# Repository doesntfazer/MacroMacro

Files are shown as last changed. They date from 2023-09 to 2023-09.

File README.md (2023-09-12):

# MacroMacro
a large gaming macro pad that runs on Vial



If you're looking to build one of your own, you can upload the **Macropad-gerber.zip** from the **gerber** folder to JLCPCB. 

If you don't feel like sodering diodes, you can upload the File in the **BOM** folder, along with the **macropad-bottom-pos.csv** in the **PIP** folder. 

You will need to solder in your hot swap sockets though. I didn't use a hot-swap Footprint that was ready for manufacturing, unfortunately. You're welcome to do this if you want to have everything but the MCU assembled by JLCPCB.

This uses a Waveshare RP2040 Zero as its MCU. Please see the image below. As you can see the 2040 is soldered in face down. This is not the conventional way of mounting these. The reason for doing it this way
is to keep the gamepad thin.


The firmware can be found in the "Firmware" folder. All you need to do is hold the boot button down while plugging it in, then you drag and drop the .UF2 file into the "drive"
I have also added the Keyboard folder in case you want to compile it yourself.

as always it will also be in the [Keyboard Dweebs Firmware repository](https://github.com/doesntfazer/Keyboard-Dweebs-Firmware-repository/tree/main) as well. 

Case files for 3d printing can be found in the "3d Models" folder as well.

You can use a soldering iron to push the threaded inserts into the case.

# Parts List
| Part | Quantity |
| --- | ---  |
| PCB | x1 |
| 1N4148W SOD-123 Diodes | x51 |
| Kailh Hot Swap Sockets | x51 |
|Cherry MX Switches | x51 |
|M2x4mmx3.5mm Threaded inserts | x7 |
| Case | x1 |
| Plate | x1 |
| M2x10 Screws | x5 |
| M2x6 Screws | x2 |

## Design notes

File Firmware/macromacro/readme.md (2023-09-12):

# macromacro

macromacro

*A short description of the keyboard/project*

* Keyboard Maintainer: [doesntfazer](https://github.com/doesntfazer)
* Hardware Supported: *The PCBs, controllers supported*
* Hardware Availability: *Links to where you can find this hardware*

Make example for this keyboard (after setting up your build environment):

    make macromacro:default

Flashing example for this keyboard:

    make macromacro:default:flash

See the [build environment setup](https://docs.qmk.fm/#/getting_started_build_tools) and the [make instructions](https://docs.qmk.fm/#/getting_started_make_guide) for more information. Brand new to QMK? Start with our [Complete Newbs Guide](https://docs.qmk.fm/#/newbs).

## Bootloader

Enter the bootloader in 3 ways:

* **Bootmagic reset**: Hold down the key at (0,0) in the matrix (usually the top left key or Escape) and plug in the keyboard
* **Physical reset button**: Briefly press the button on the back of the PCB - some may have pads you must short instead
* **Keycode in layout**: Press the key mapped to `QK_BOOT` if it is available

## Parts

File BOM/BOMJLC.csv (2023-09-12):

Comment | Designator | Footprint | LCSC Part #
1N4148W | D1, D2, D3, D4, D5, D6, D7, D8, D9, D10, D11, D12, D13, D14, D15, D16, D17, D18, D19, D20, D21, D22, D23, D24, D25, D26, D27, D28, D29, D30, D31, D32, D33, D34, D35, D36, D37, D38, D39, D40, D41, D42, D43, D44, D45, D46, D47, D48, D49, D50, D51 | D_SOD-123 | C81598
SW_PUSH | SW1, SW2, SW3, SW4, SW5, SW6, SW7, SW8, SW9, SW10, SW11, SW12, SW13, SW14, SW15, SW16, SW17, SW18, SW19, SW20, SW21, SW22, SW23, SW24, SW25, SW26, SW27, SW28, SW29, SW30, SW31, SW32, SW33, SW34, SW35, SW36, SW37, SW38, SW39, SW40, SW41, SW42, SW43, SW44, SW45, SW46, SW47, SW48, SW49, SW50, SW51 | Kailh_socket_MX_4fab | C5156480

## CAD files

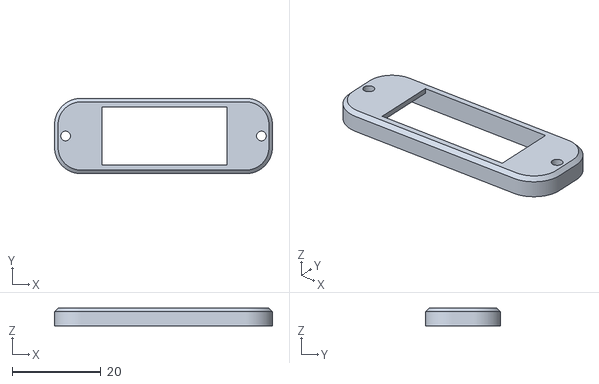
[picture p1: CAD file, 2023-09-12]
3d Models/bigger cover.stl
49.2 x 17.0 x 4.00

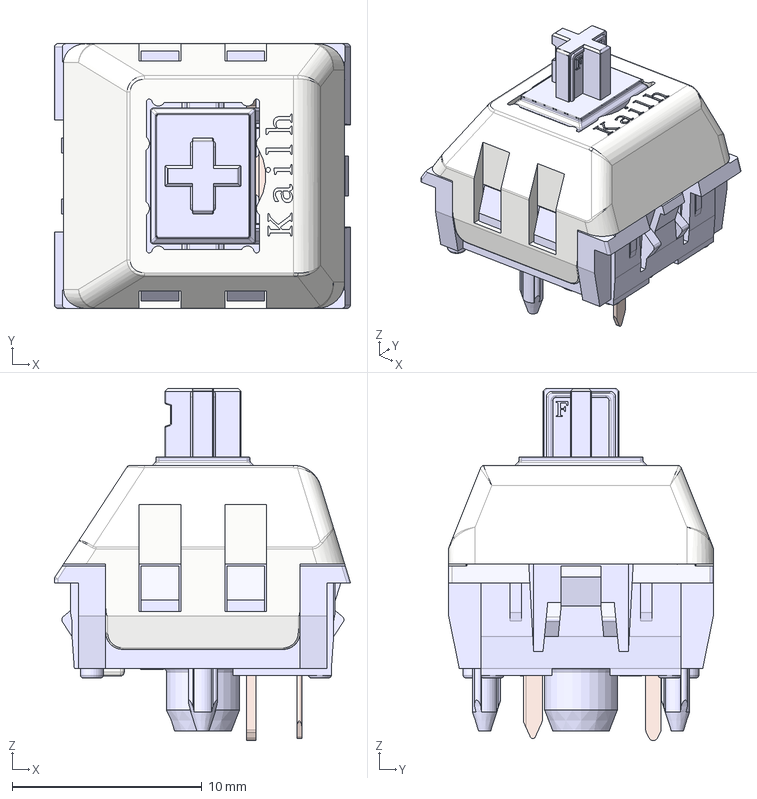
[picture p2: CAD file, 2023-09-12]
components/Kailh Polia.step
15.6 x 14.0 x 18.5 mm
Housing
ThickContact
SpringContact
Stem
Lid

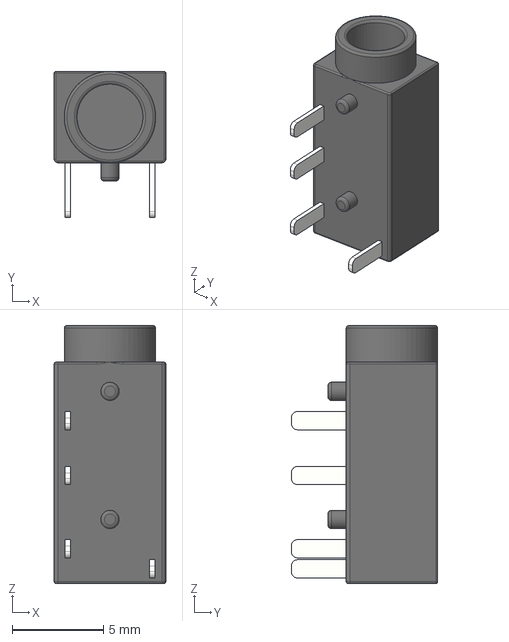
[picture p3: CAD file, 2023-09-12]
components/Keebio-Parts.pretty-master/3dmodels/PJ-320A.step
6.10 x 8.00 x 14.1 mm

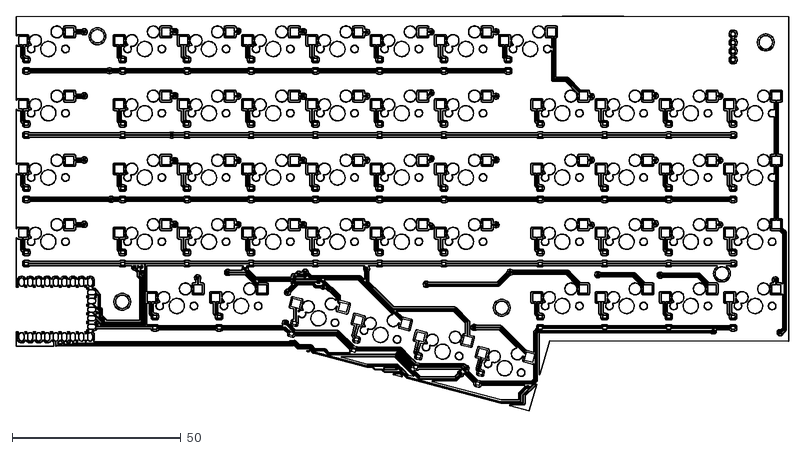
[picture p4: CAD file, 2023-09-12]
DXF/macropad-B_Cu.dxf
229.1 x 116.9

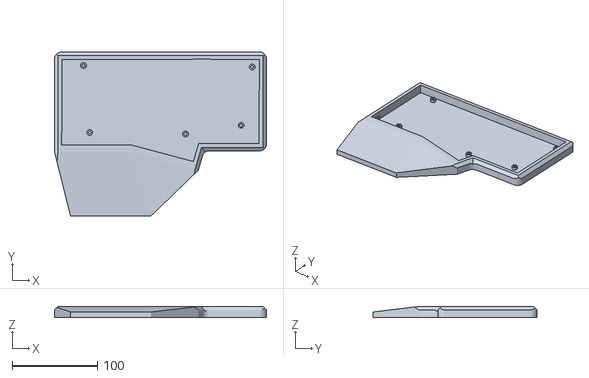
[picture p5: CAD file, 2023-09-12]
3d Models/case.stl
249.1 x 192.6 x 13.0

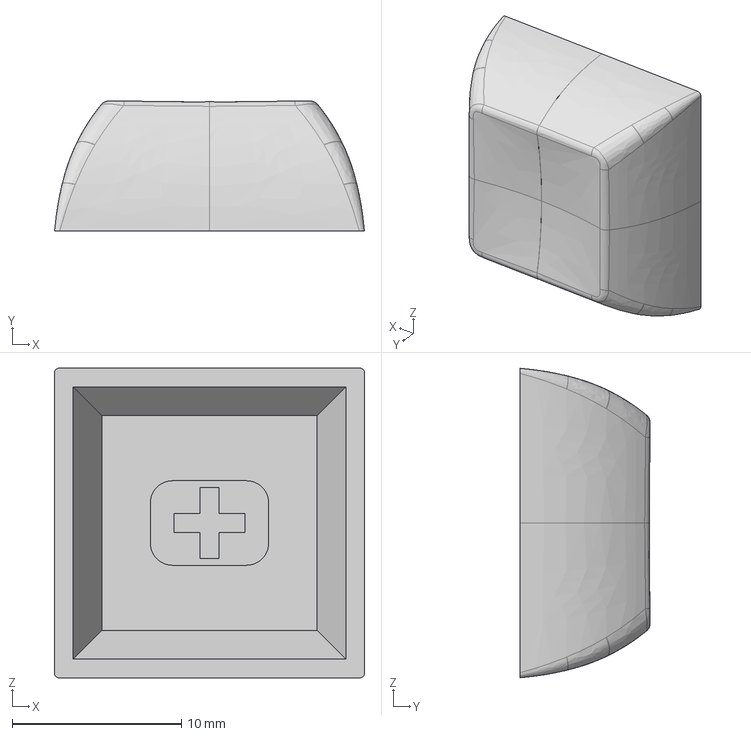
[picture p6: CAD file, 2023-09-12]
components/DSA_Keycap_CherryMX.step
18.3 x 7.69 x 18.3 mm

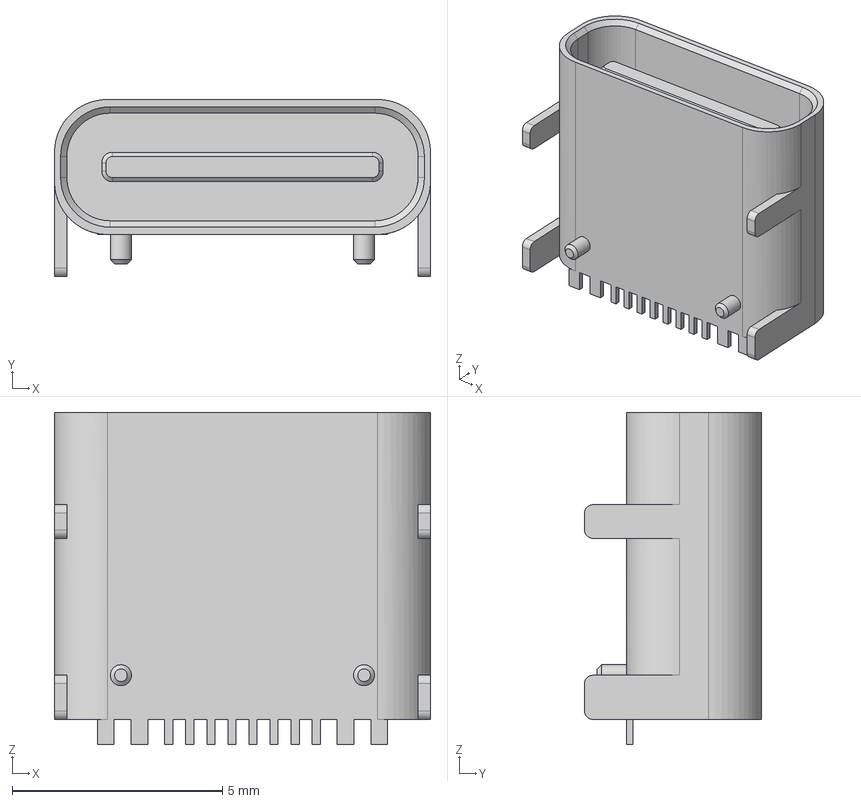
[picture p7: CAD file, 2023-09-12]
components/Keebio-Parts.pretty-master/3dmodels/HRO TYPE-C-31-M-12.step
8.94 x 4.21 x 7.90 mm

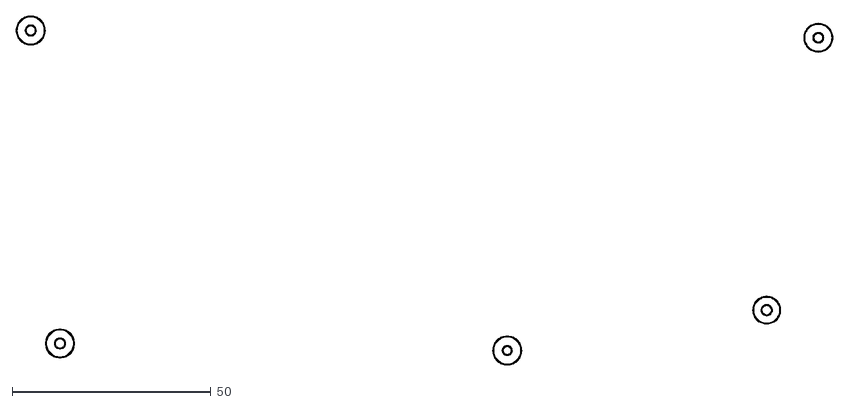
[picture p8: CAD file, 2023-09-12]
DXF/macropad-User_6.dxf
205.4 x 87.7

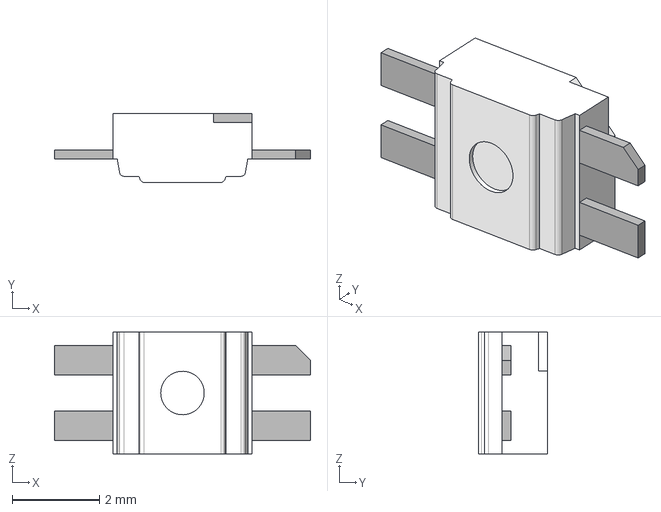
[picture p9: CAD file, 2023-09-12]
components/Keebio-Parts.pretty-master/3dmodels/SK6812MINI-E v1.step
5.88 x 1.58 x 2.80 mm

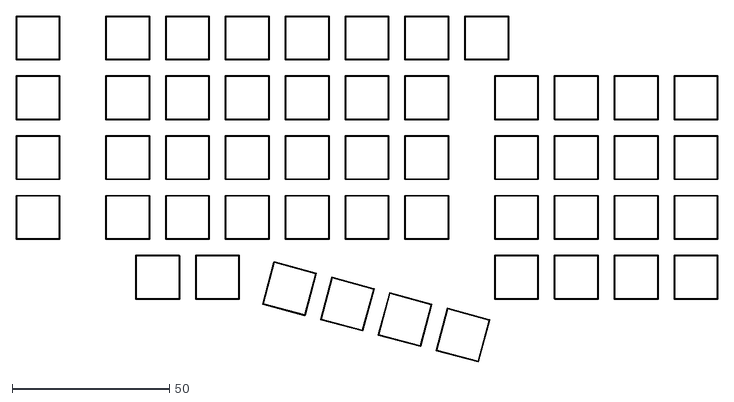
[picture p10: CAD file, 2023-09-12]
DXF/macropad-User_Eco2.dxf
223.5 x 110.2

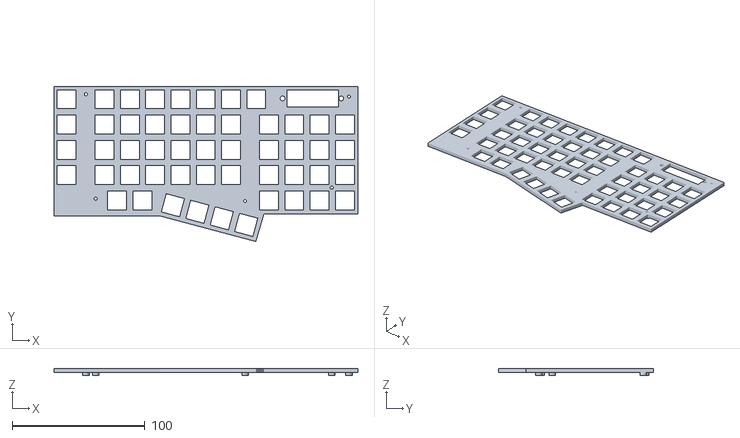
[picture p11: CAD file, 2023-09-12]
3d Models/plate.stl
229.1 x 116.8 x 5.00

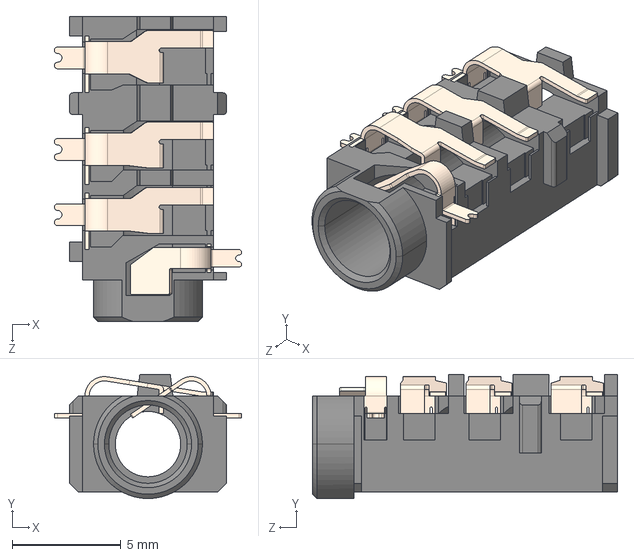
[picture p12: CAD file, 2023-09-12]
components/Keebio-Parts.pretty-master/3dmodels/CUI_SJ-43614-SMT-TR.step
8.60 x 5.70 x 14.0 mm

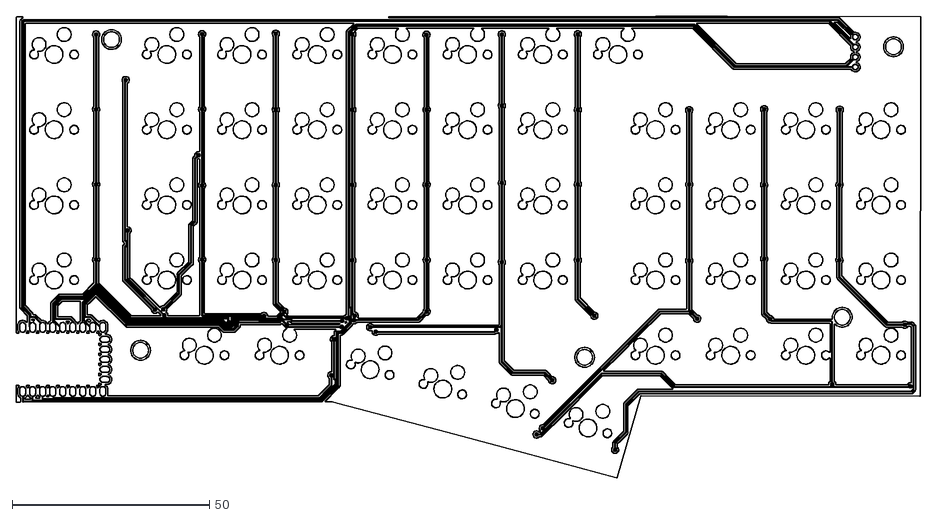
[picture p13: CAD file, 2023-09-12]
DXF/macropad-F_Cu.dxf
229.1 x 116.9

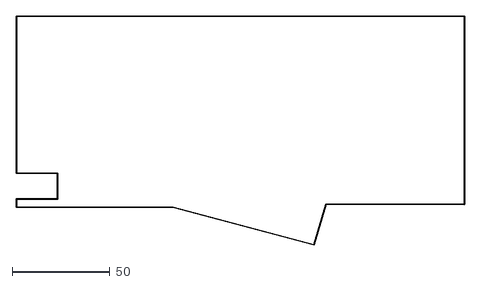
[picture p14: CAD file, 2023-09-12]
DXF/macropad-Edge_Cuts.dxf
229.2 x 117.0

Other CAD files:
3d Models/oled cover.stl
3d Models/plate-low.stl
components/Molex/0781271220.stp
DXF/macropad-B_Mask.dxf
DXF/macropad-B_Paste.dxf
DXF/macropad-B_Silkscreen.dxf
DXF/macropad-F_Mask.dxf
DXF/macropad-F_Paste.dxf
DXF/macropad-F_Silkscreen.dxf
components/KiCad-RP-Pico-main/SketchUp Model/Pico.skp

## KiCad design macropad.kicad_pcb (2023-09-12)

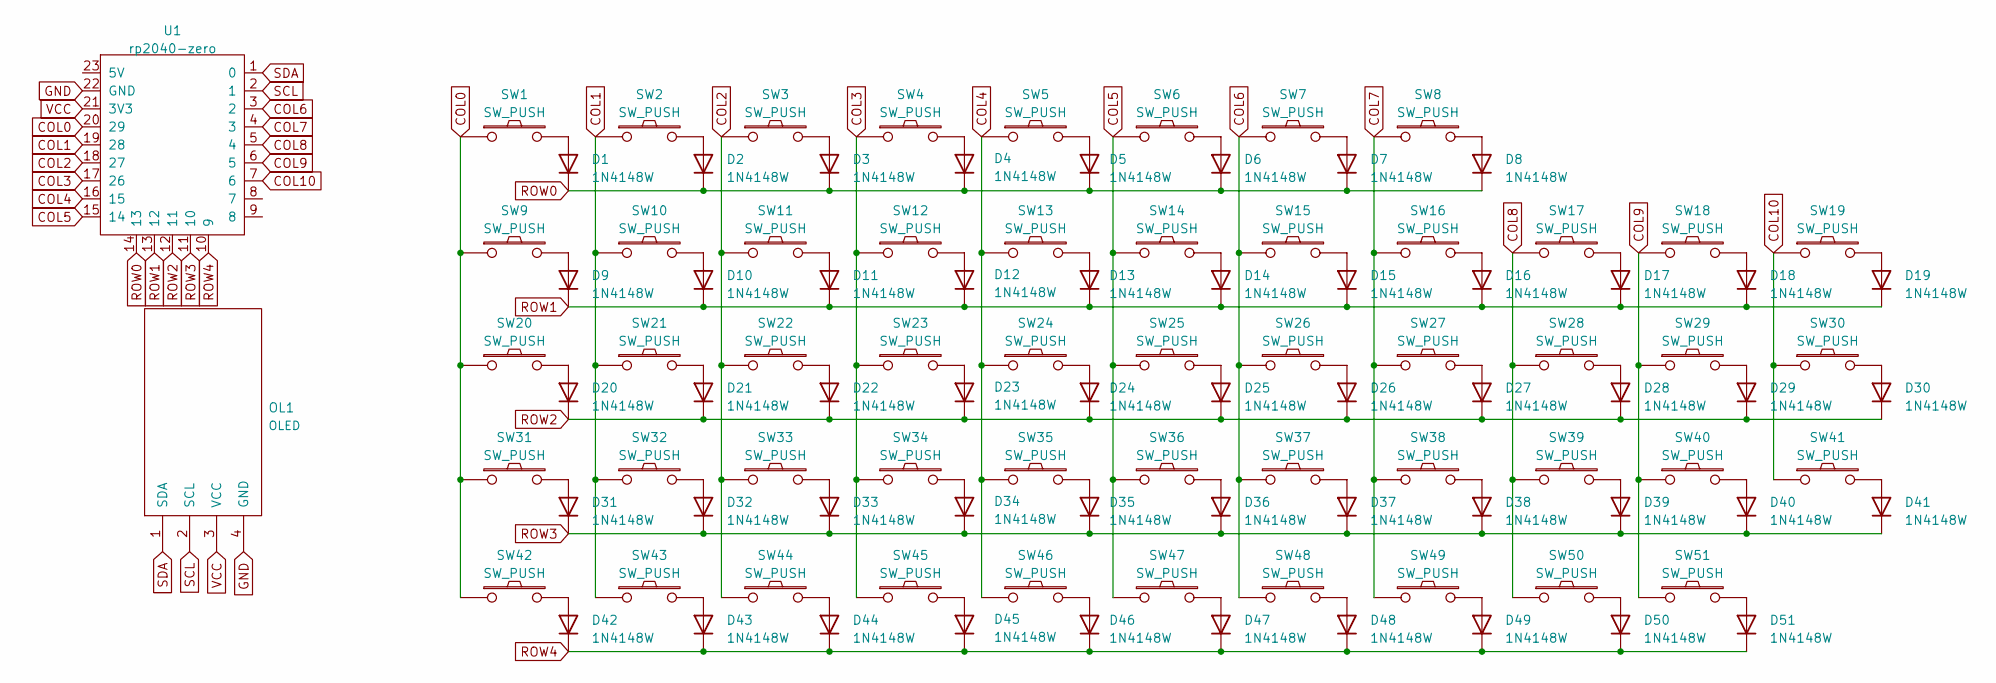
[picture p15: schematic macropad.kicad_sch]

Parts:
D1, D2, D3, D4, D5, D6, D7, D8, D9, D10, D11, D12, D13, D14, D15, D16, D17, D18, D19, D20, D21, D22, D23, D24, D25, D26, D27, D28, D29, D30, D31, D32, D33, D34, D35, D36, D37, D38, D39, D40, D41, D42, D43, D44, D45, D46, D47, D48, D49, D50, D51: 1N4148W; D_SOD-123
OL1: OLED; OLED_v2
SW1, SW2, SW3, SW4, SW5, SW6, SW7, SW8, SW9, SW10, SW11, SW12, SW13, SW14, SW15, SW16, SW17, SW18, SW19, SW20, SW21, SW22, SW23, SW24, SW25, SW26, SW27, SW28, SW29, SW30, SW31, SW32, SW33, SW34, SW35, SW36, SW37, SW38, SW39, SW40, SW41, SW42, SW43, SW44, SW45, SW46, SW47, SW48, SW49, SW50, SW51: SW_PUSH; Kailh_socket_MX
U1: rp2040-zero; rp2040-zero-tht-nocut

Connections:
COL0: SW1.1, SW9.1, SW20.1, SW31.1, SW42.1, U1.20 (29)
COL1: SW2.1, SW10.1, SW21.1, SW32.1, SW43.1, U1.19 (28)
COL2: SW3.1, SW11.1, SW22.1, SW33.1, SW44.1, U1.18 (27)
COL3: SW4.1, SW12.1, SW23.1, SW34.1, SW45.1, U1.17 (26)
COL4: SW5.1, SW13.1, SW24.1, SW35.1, SW46.1, U1.16 (15)
COL5: SW6.1, SW14.1, SW25.1, SW36.1, SW47.1, U1.15 (14)
COL6: SW7.1, SW15.1, SW26.1, SW37.1, SW48.1, U1.3 (2)
COL7: SW8.1, SW16.1, SW27.1, SW38.1, SW49.1, U1.4 (3)
COL8: SW17.1, SW28.1, SW39.1, SW50.1, U1.5 (4)
COL9: SW18.1, SW29.1, SW40.1, SW51.1, U1.6 (5)
COL10: SW19.1, SW30.1, SW41.1, U1.7 (6)
GND: OL1.4 (GND), U1.22 (GND)
unnamed: D1.2 (A), SW1.2
unnamed: D2.2 (A), SW2.2
unnamed: D3.2 (A), SW3.2
unnamed: D4.2 (A), SW4.2
unnamed: D5.2 (A), SW5.2
unnamed: D6.2 (A), SW6.2
unnamed: D7.2 (A), SW7.2
unnamed: D8.2 (A), SW8.2
unnamed: D9.2 (A), SW9.2
unnamed: D10.2 (A), SW10.2
unnamed: D11.2 (A), SW11.2
unnamed: D12.2 (A), SW12.2
unnamed: D13.2 (A), SW13.2
unnamed: D14.2 (A), SW14.2
unnamed: D15.2 (A), SW15.2
unnamed: D16.2 (A), SW16.2
unnamed: D17.2 (A), SW17.2
unnamed: D18.2 (A), SW18.2
unnamed: D19.2 (A), SW19.2
unnamed: D20.2 (A), SW20.2
unnamed: D21.2 (A), SW21.2
unnamed: D22.2 (A), SW22.2
unnamed: D23.2 (A), SW23.2
unnamed: D24.2 (A), SW24.2
unnamed: D25.2 (A), SW25.2
unnamed: D26.2 (A), SW26.2
unnamed: D27.2 (A), SW27.2
unnamed: D28.2 (A), SW28.2
unnamed: D29.2 (A), SW29.2
unnamed: D30.2 (A), SW30.2
unnamed: D31.2 (A), SW31.2
unnamed: D32.2 (A), SW32.2
unnamed: D33.2 (A), SW33.2
unnamed: D34.2 (A), SW34.2
unnamed: D35.2 (A), SW35.2
unnamed: D36.2 (A), SW36.2
unnamed: D37.2 (A), SW37.2
unnamed: D38.2 (A), SW38.2
unnamed: D39.2 (A), SW39.2
unnamed: D40.2 (A), SW40.2
unnamed: D41.2 (A), SW41.2
unnamed: D42.2 (A), SW42.2
unnamed: D43.2 (A), SW43.2
unnamed: D44.2 (A), SW44.2
unnamed: D45.2 (A), SW45.2
unnamed: D46.2 (A), SW46.2
unnamed: D47.2 (A), SW47.2
unnamed: D48.2 (A), SW48.2
unnamed: D49.2 (A), SW49.2
unnamed: D50.2 (A), SW50.2
unnamed: D51.2 (A), SW51.2
ROW0: D1.1 (K), D2.1 (K), D3.1 (K), D4.1 (K), D5.1 (K), D6.1 (K), D7.1 (K), D8.1 (K), U1.14 (13)
ROW1: D9.1 (K), D10.1 (K), D11.1 (K), D12.1 (K), D13.1 (K), D14.1 (K), D15.1 (K), D16.1 (K), D17.1 (K), D18.1 (K), D19.1 (K), U1.13 (12)
ROW2: D20.1 (K), D21.1 (K), D22.1 (K), D23.1 (K), D24.1 (K), D25.1 (K), D26.1 (K), D27.1 (K), D28.1 (K), D29.1 (K), D30.1 (K), U1.12 (11)
ROW3: D31.1 (K), D32.1 (K), D33.1 (K), D34.1 (K), D35.1 (K), D36.1 (K), D37.1 (K), D38.1 (K), D39.1 (K), D40.1 (K), D41.1 (K), U1.11 (10)
ROW4: D42.1 (K), D43.1 (K), D44.1 (K), D45.1 (K), D46.1 (K), D47.1 (K), D48.1 (K), D49.1 (K), D50.1 (K), D51.1 (K), U1.10 (9)
SCL: OL1.2 (SCL), U1.2 (1)
SDA: OL1.1 (SDA), U1.1 (0)
VCC: OL1.3 (VCC), U1.21 (3V3)

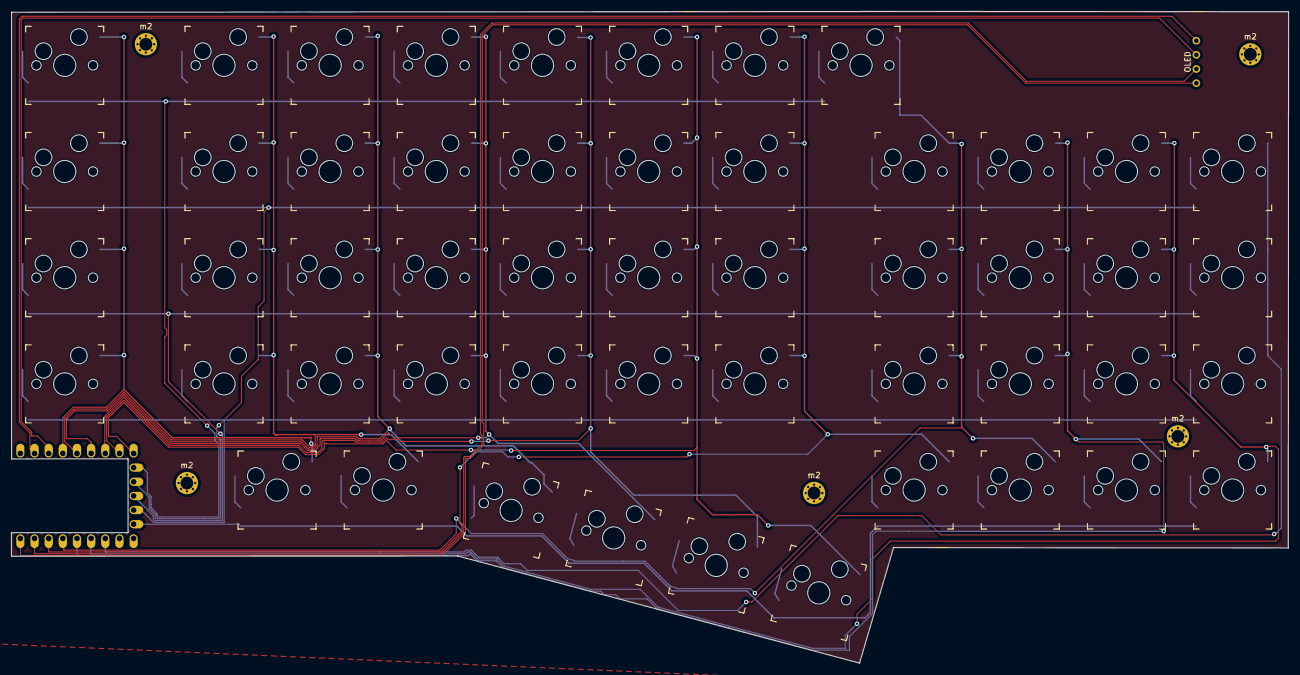
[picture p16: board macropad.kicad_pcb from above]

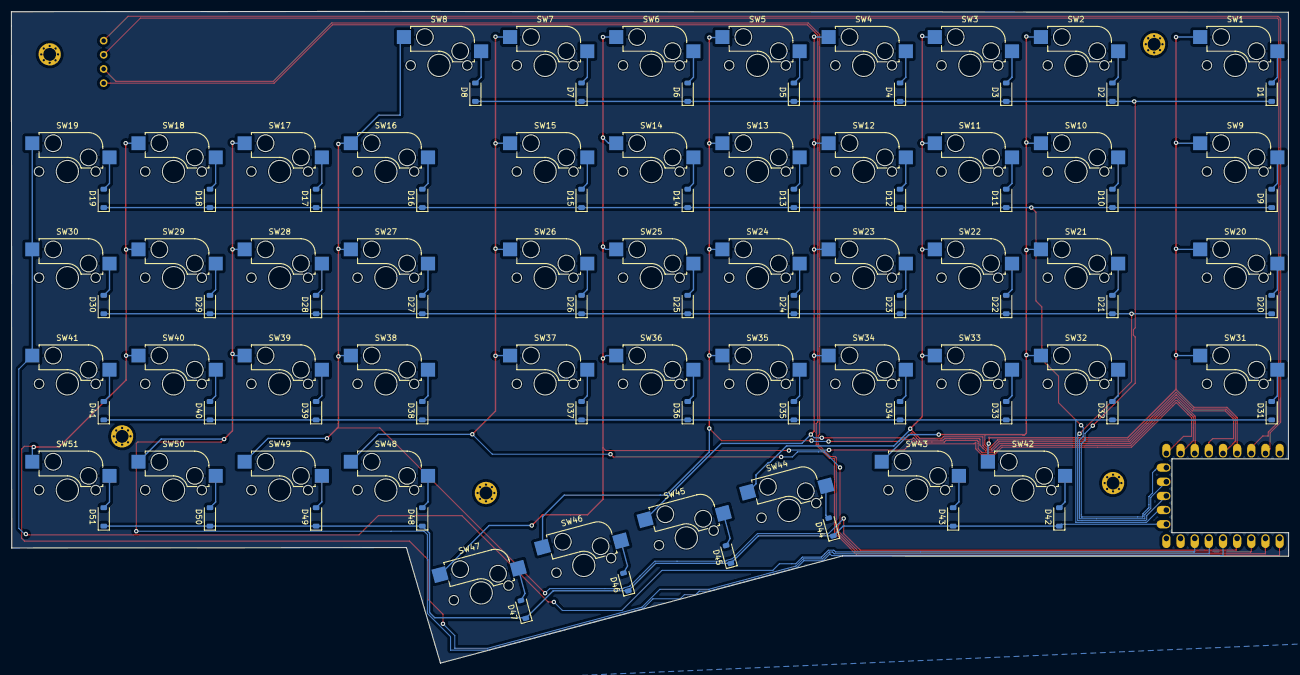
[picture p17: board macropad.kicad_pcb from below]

Board: 2 copper layers, 229.2 x 116.9 mm, 109 parts (52 on the bottom side), 71 nets.

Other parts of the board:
m2, m2#2, m2#3, m2#4, m2#5: m2; M2_HOLE_v3

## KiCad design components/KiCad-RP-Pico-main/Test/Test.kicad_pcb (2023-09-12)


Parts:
J1, J2: Conn_01x20; PinSocket_1x20_P1.00mm_Vertical
J3: Conn_01x03; PinSocket_1x03_P1.00mm_Vertical
U1: Pico; RPi_Pico_SMD_TH

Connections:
GND: J1.3, J1.8, J1.13, J1.18, J2.3, J2.13, J2.18, J3.2, U1.3 (GND), U1.8 (GND), U1.13 (GND), U1.18 (GND), U1.23 (GND), U1.28 (GND), U1.38 (GND), U1.42 (GND)
unnamed: J1.1, U1.1 (GPIO0)
unnamed: J1.2, U1.2 (GPIO1)
unnamed: J1.4, U1.4 (GPIO2)
unnamed: J1.5, U1.5 (GPIO3)
unnamed: J1.6, U1.6 (GPIO4)
unnamed: J1.7, U1.7 (GPIO5)
unnamed: J1.9, U1.9 (GPIO6)
unnamed: J1.10, U1.10 (GPIO7)
unnamed: J1.11, U1.11 (GPIO8)
unnamed: J1.12, U1.12 (GPIO9)
unnamed: J1.14, U1.14 (GPIO10)
unnamed: J1.15, U1.15 (GPIO11)
unnamed: J1.16, U1.16 (GPIO12)
unnamed: J1.17, U1.17 (GPIO13)
unnamed: J1.19, U1.19 (GPIO14)
unnamed: J1.20, U1.20 (GPIO15)
unnamed: J2.1, U1.40 (VBUS)
unnamed: J2.2, U1.39 (VSYS)
unnamed: J2.4, U1.37 (3V3_EN)
unnamed: J2.5, U1.36 (3V3)
unnamed: J2.6, U1.35 (ADC_VREF)
unnamed: J2.7, U1.34 (GPIO28_ADC2)
unnamed: J2.8, U1.33 (AGND)
unnamed: J2.9, U1.32 (GPIO27_ADC1)
unnamed: J2.10, U1.31 (GPIO26_ADC0)
unnamed: J2.11, U1.30 (RUN)
unnamed: J2.12, U1.29 (GPIO22)
unnamed: J2.14, U1.27 (GPIO21)
unnamed: J2.15, U1.26 (GPIO20)
unnamed: J2.16, U1.25 (GPIO19)
unnamed: J2.17, U1.24 (GPIO18)
unnamed: J2.19, U1.22 (GPIO17)
unnamed: J2.20, U1.21 (GPIO16)
unnamed: J3.1, U1.43 (SWDIO)
unnamed: J3.3, U1.41 (SWCLK)


Board: 2 copper layers, 43.0 x 65.0 mm, 4 parts (0 on the bottom side), 36 nets.

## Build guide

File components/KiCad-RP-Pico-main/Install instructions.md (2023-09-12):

# Install instructions

## 1. Copy the files locally

Copy the `RP-Pico Libraries` folder wherever you like on your computer.

## 2. Install the Raspberry Pi Pico board schema symbol

Use the `KiCad | Preferences | Manage Symbol Libraries...` command to manage the symbol library:



then select the global tab and click on the folder button:



navigate to the `RP-Pico Libraries` folder, select the `MCU_RaspberryPi_and_Boards.kicad_sym` file and open it:



et voilà, the first step is completed:



You can now close the symbol libraries manager window.

## 3. Install the Raspberry Pi Pico board footprint

You can use a similar approach to add the footprint to the footprint libraries manager, but I've found some issues that I've solved using the footprint editor, so here are the steps I suggest you to follow:

Open the footprint editor



wait for the footprints to load... then use the `File | Add Library` command:



confirm the `Global` choice:



and select the `MCU_RaspberriPi_and_Boards.pretty` folder (yes, the folder represent a footprint library on KiCad):



Now the library is installed on KiCad with the Raspberry Pi Pico footprint (double click on it to see it on the editor pane):



Don't close the windows as the next step start from here.

## 4. Install the Raspberry Pi Pico board footprint 3D visual

If not already open, open the the footprint editor

symbol library manager

double click on the `RPi_Pico_SMD_TH` footprint from the `MCU_RaspberriPi_and_Boards` library and then click on the `Footprint properties` icon:



In the footprint properties window, first select the `3D Settings` tab. Please note that the preview shows only the PCB board with the footprint added on step 3, without any 3D representation of the Raspberry Pi Pico board. Now click on the folder icon to add the 3D model:



Navigate to the `RP-Pico Libraries` folder, select the `Pico.wrl` file and wait until the model is shown in the right panel, then confirm with OK:



The model is already scaled and translated to match the footprint:



now close the `Footprint Properties` window, and the `Footprint Editor`, obviously saving the changes.

## Conclusion

Now that you've installed the schema and footprint and added the 3D model to the footprint, you can use the Raspberry Pi Pico board on your KiCad projects.

I've also added a test KiCad Project on the `Test` folder, that you can use to see an example of it.

Have fun!
